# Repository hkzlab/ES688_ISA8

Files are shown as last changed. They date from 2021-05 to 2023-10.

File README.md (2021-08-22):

# ES688F / OPL3 8bit ISA Sound Card

## Introduction

This is a sound card for the ISA 8bit bus sporting the **ES688F** chip by *ESS Technology* and the **YMF262** chip by *Yamaha*, also known as the **OPL3**.

This board provides selectable **Sound Blaster PRO** / **Sound Blaster** emulation and **OPL3** compatibility.

It's completely jumper-configurable, requiring no software except the *essvol* utility to set the volume.

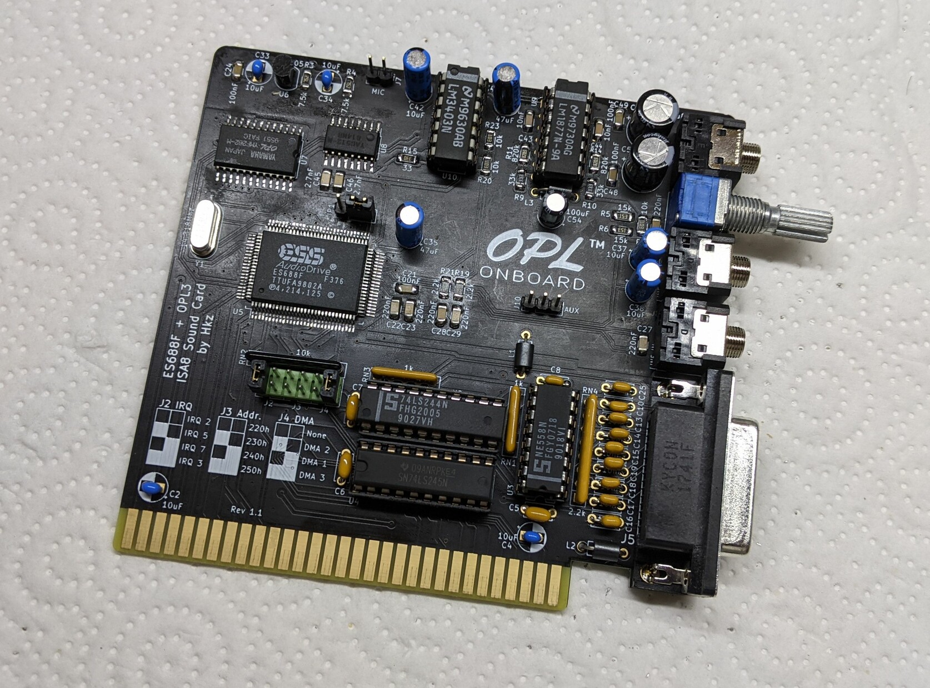
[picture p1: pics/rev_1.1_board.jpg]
Rev. 1.1 Board


This board provides the following connections:

* Speaker out (amplified)
* Line out
* Line in
* Aux in (internal header)
* Microphone in (internal header)
* Joystick port
* MIDI on Joystick port
* Volume regulation pot

### Disclaimer

I take NO responsibility for what happens if you decide to build and use this card. Your computer might crash, catch fire or be destroyed in other nasty ways.
You're encourauged to take what you deem fit from this, and use it in your projects!

### Functionalities

✅ means I tested the functionality and it works, ❌ means I tested the functionality and found issues, ? means that the functionality has yet to be tested.

* [✅] FM Synthesis via OPL3
* [✅] Digital audio playback
* [?] Stereo (left/right channel) check
* [✅] Joystick port
* [✅] Speaker Out (amplified)
* [✅] Line out
* [✅] Line in
* [?] AUX In
* [?] Microphone in
* [✅] MIDI output via Joystick port

The card was tested on:

* [✅] NEC V20 9.5Mhz / DOS 6.22
* [✅] SUNTAC 286 12Mhz motherboard / DOS 6.22

## Configuration

This card is configured via jumpers.

* **JP1**: Selects the **Sound Blaster emulation mode**
  * 1-2: Sound Blaster (DSP v2.11)
  * 2-3 Sound Blaster PRO (DSP v3.1)
  
The following jumpers must me insalled vertically in the block. **1** means **Jumper Present**, **0** means **Jumper Absent**.

* **J2**: Selects the IRQ:
  * 00: IRQ2
  * 10: IRQ5 (default)
  * 01: IRQ7
  * 11: IRQ3
* **J3**: Selects the I/O address:
  * 00: 220h (default)
  * 10: 230h
  * 01: 240h
  * 11: 250h
* **J4**: Selects the DMA channel
  * 00: None
  * 10: DMA2
  * 01: DMA1 (default)
  * 11: DMA3
  
  **WARNING**: /DACK2 and DRQ2 lines are disconnected and must be jumpered on the backside of the board if used, by bridging JP3 and JP2.

## Bill of Materials

**TODO**

## Known Issues

### Rev 1.1

* Missing silkscreen to describe JP1

### Rev 1.0

* Wrong footprints for YAC512 and YMF262 chips
* Volume pot placed after audio decoupling. Wrong.

## Credits

Thanks to [Sergey Kiselev](https://github.com/skiselev) for his symbol/footprint library!

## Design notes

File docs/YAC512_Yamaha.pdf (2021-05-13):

www.DataSheet4U.com

www.DataSheet4U.com

www.DataSheet4U.com

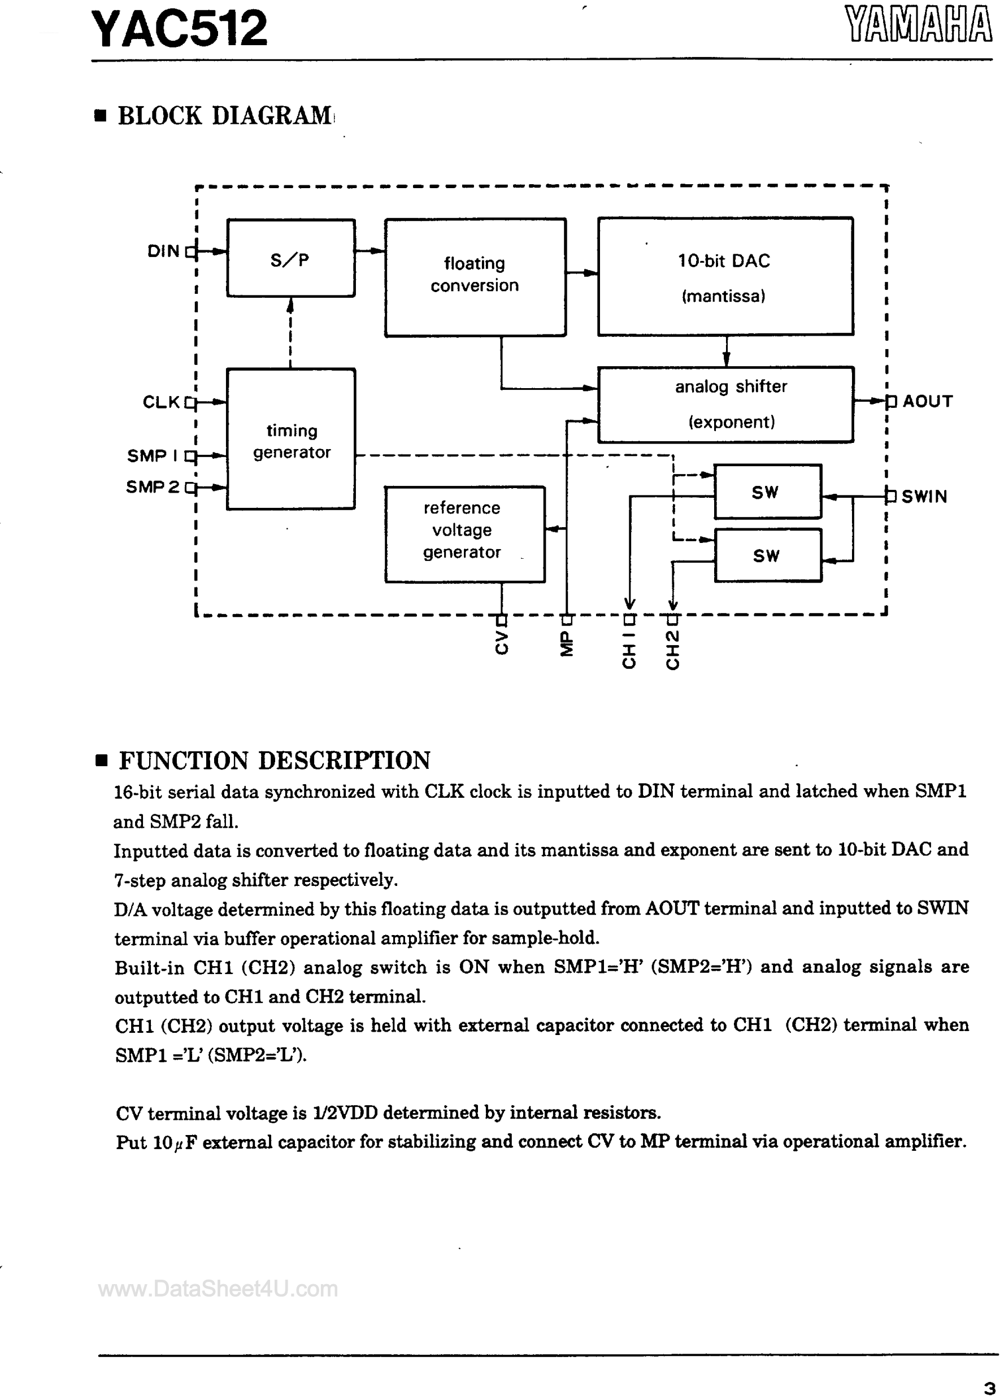
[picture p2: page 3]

www.DataSheet4U.com

www.DataSheet4U.com

www.DataSheet4U.com

www.DataSheet4U.com

www.DataSheet4U.com

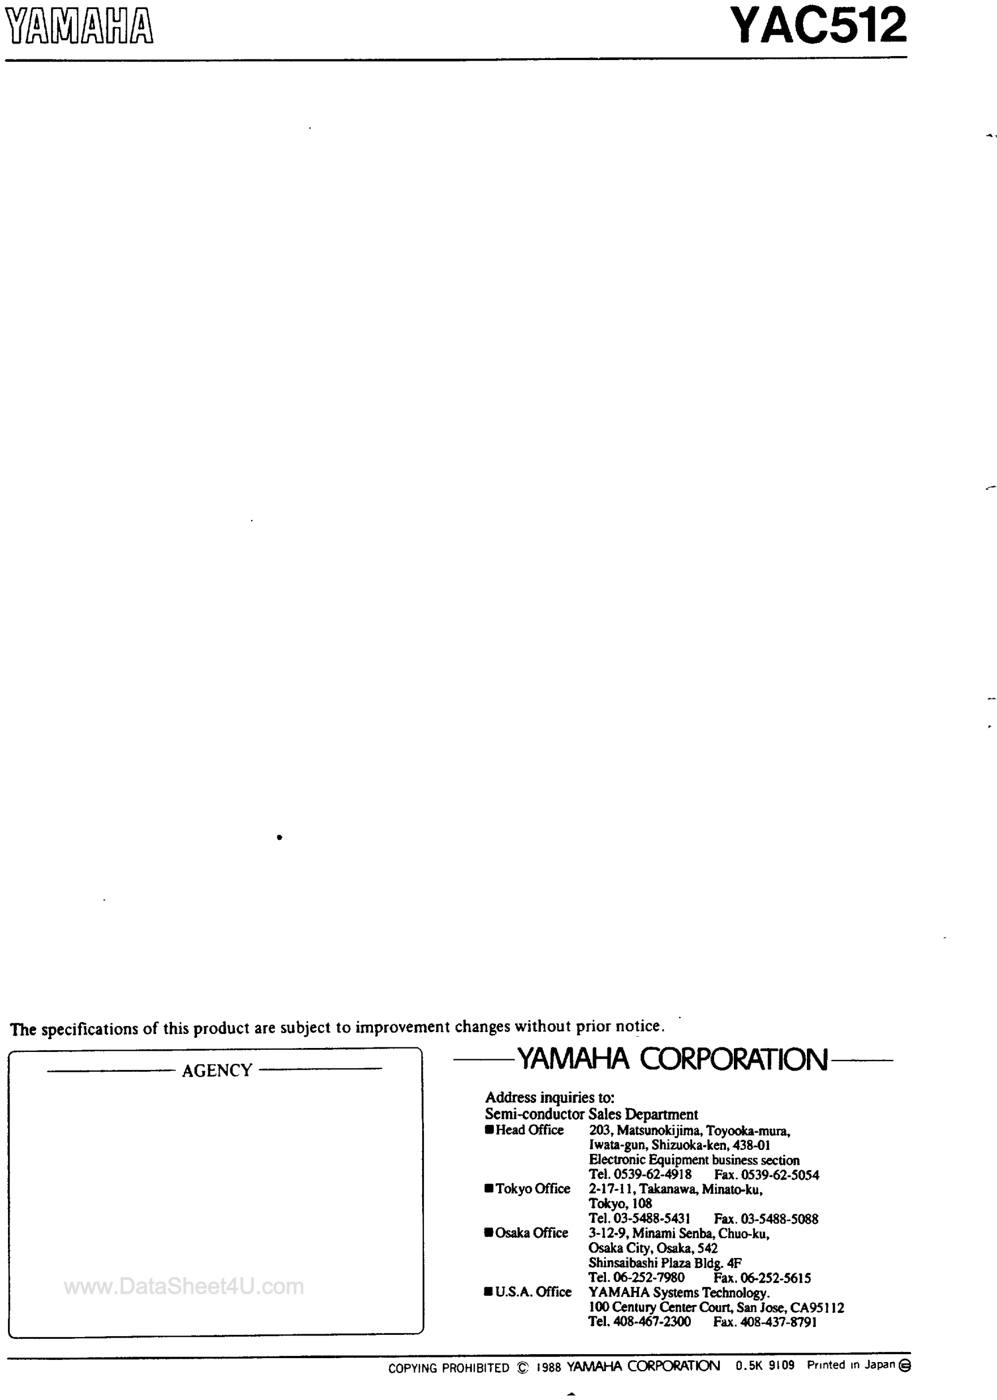
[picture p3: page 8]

www.DataSheet4U.com

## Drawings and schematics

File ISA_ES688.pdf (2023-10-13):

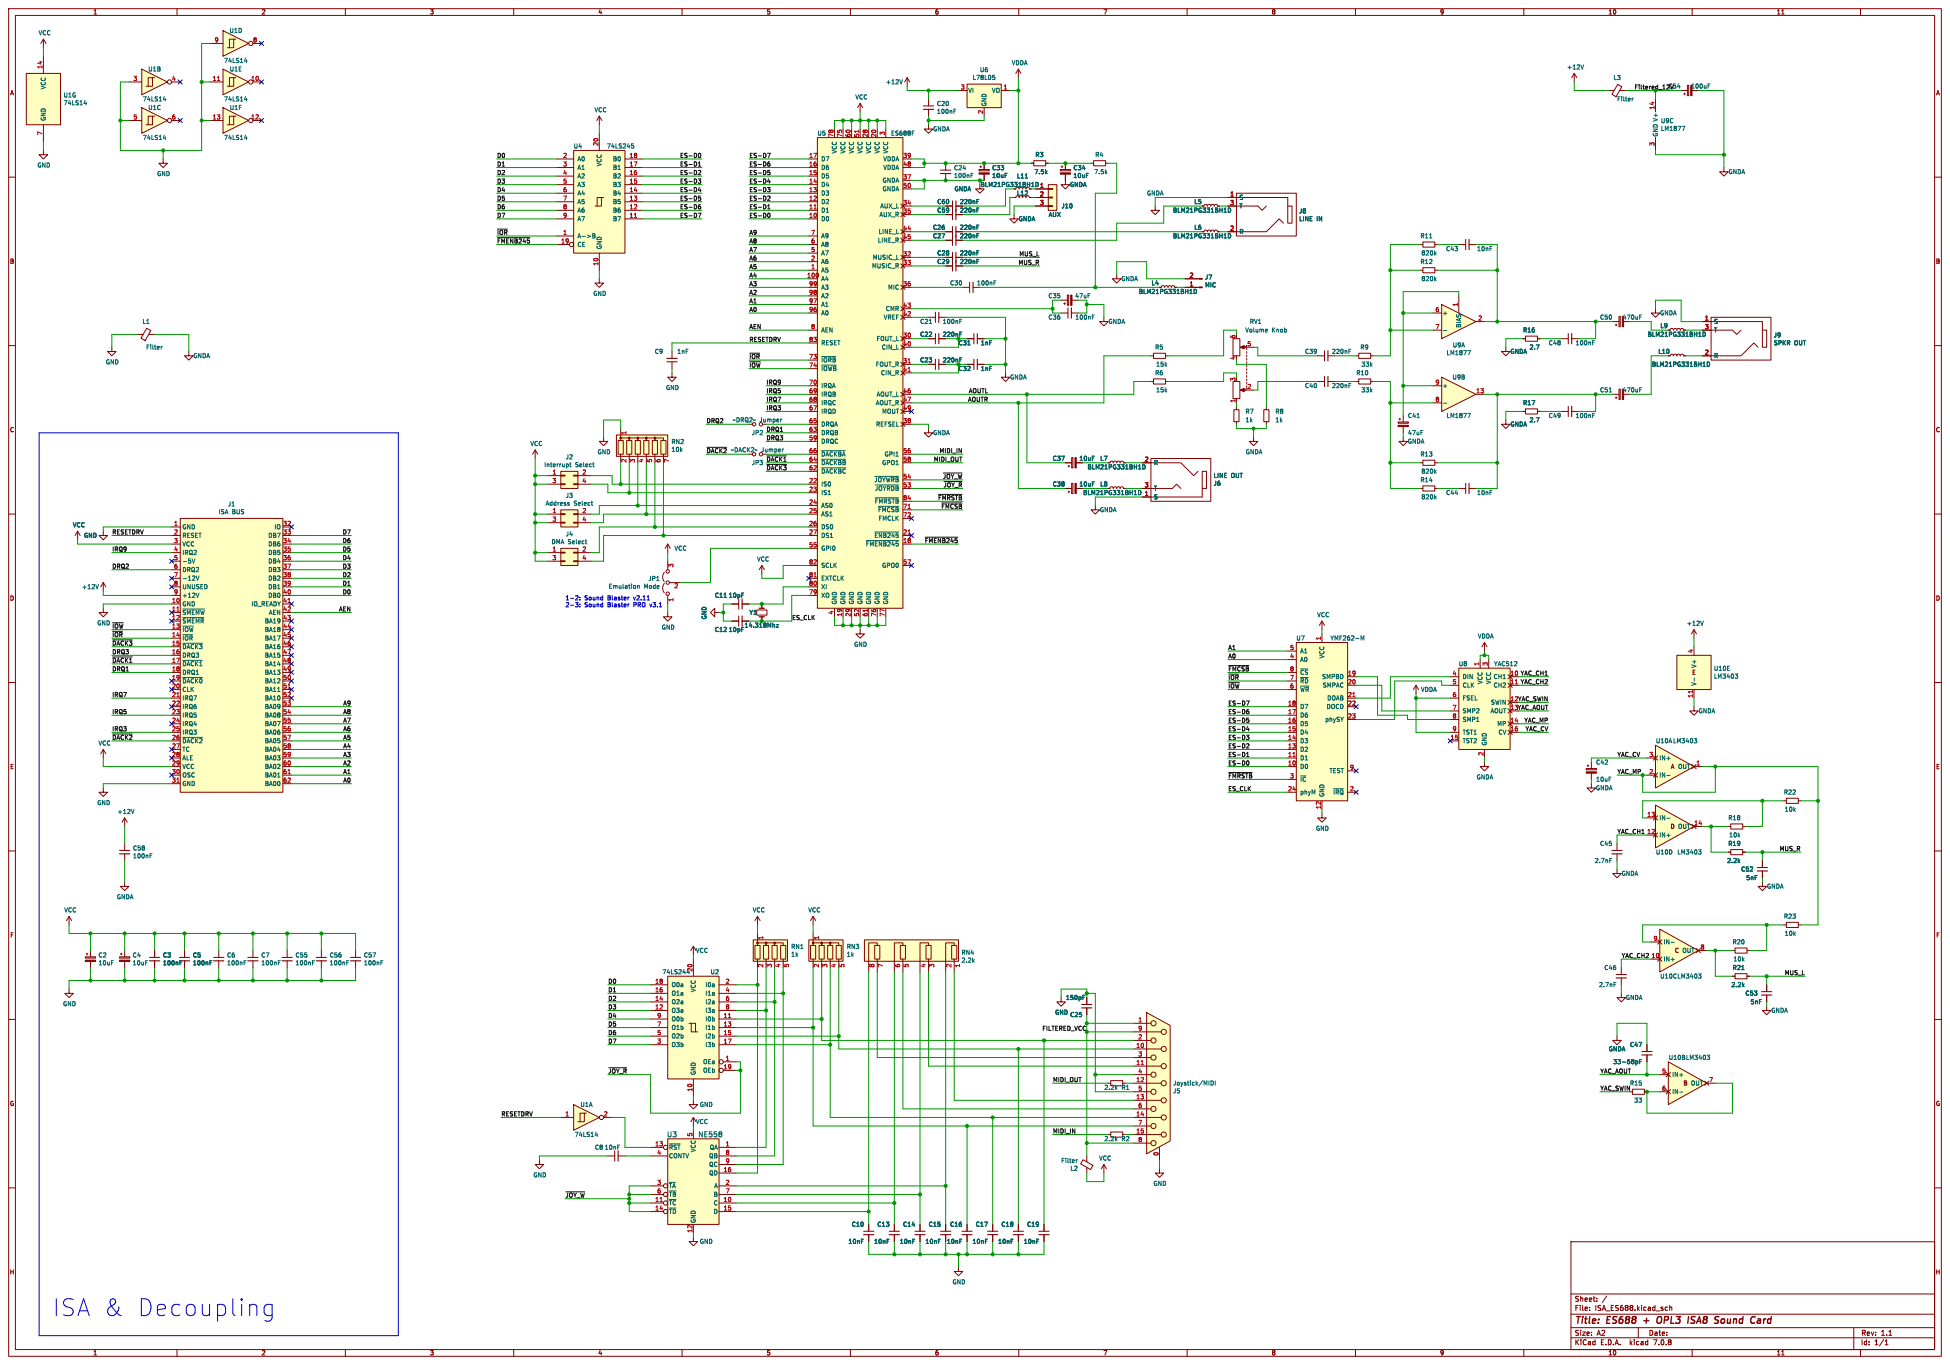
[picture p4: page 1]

3 FOUT_L 30 FOUT_R 31 MUSIC_L 32 MUSIC_R 33 AUX_L 34 AUX_R 35 MIC 36 GNDA 37 REFSEL 38 VDDA 39 GND

ES-D3 ES-D2 ES-D1 ES-D4 ~{IOW} D1

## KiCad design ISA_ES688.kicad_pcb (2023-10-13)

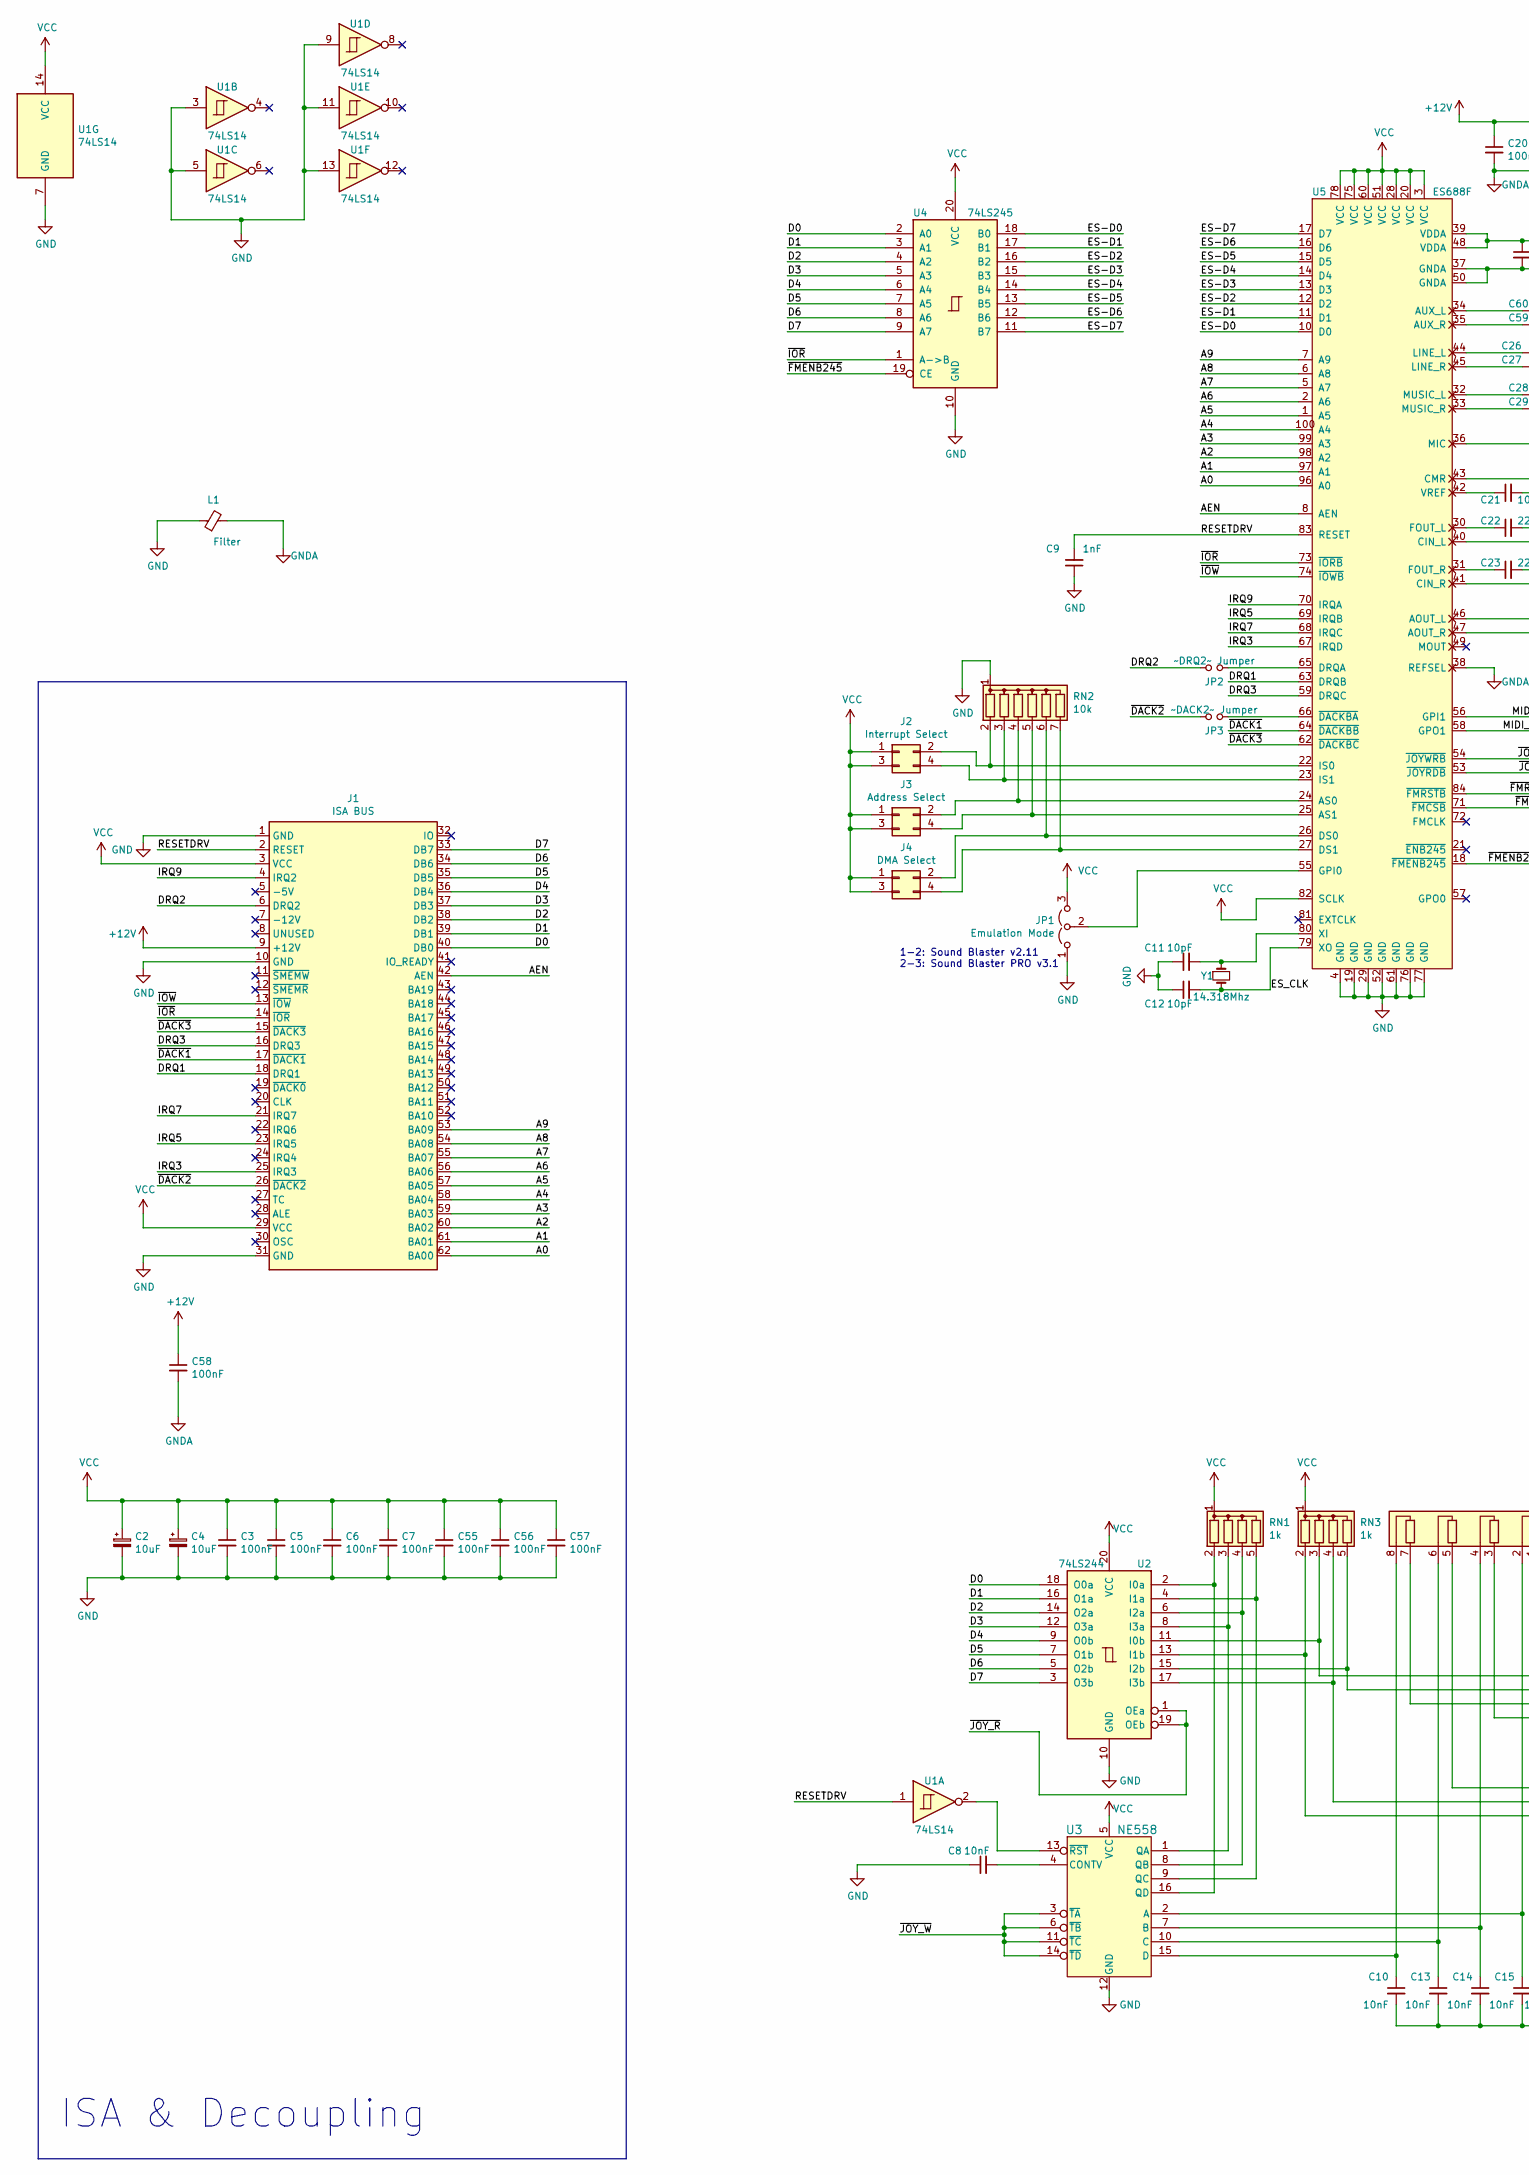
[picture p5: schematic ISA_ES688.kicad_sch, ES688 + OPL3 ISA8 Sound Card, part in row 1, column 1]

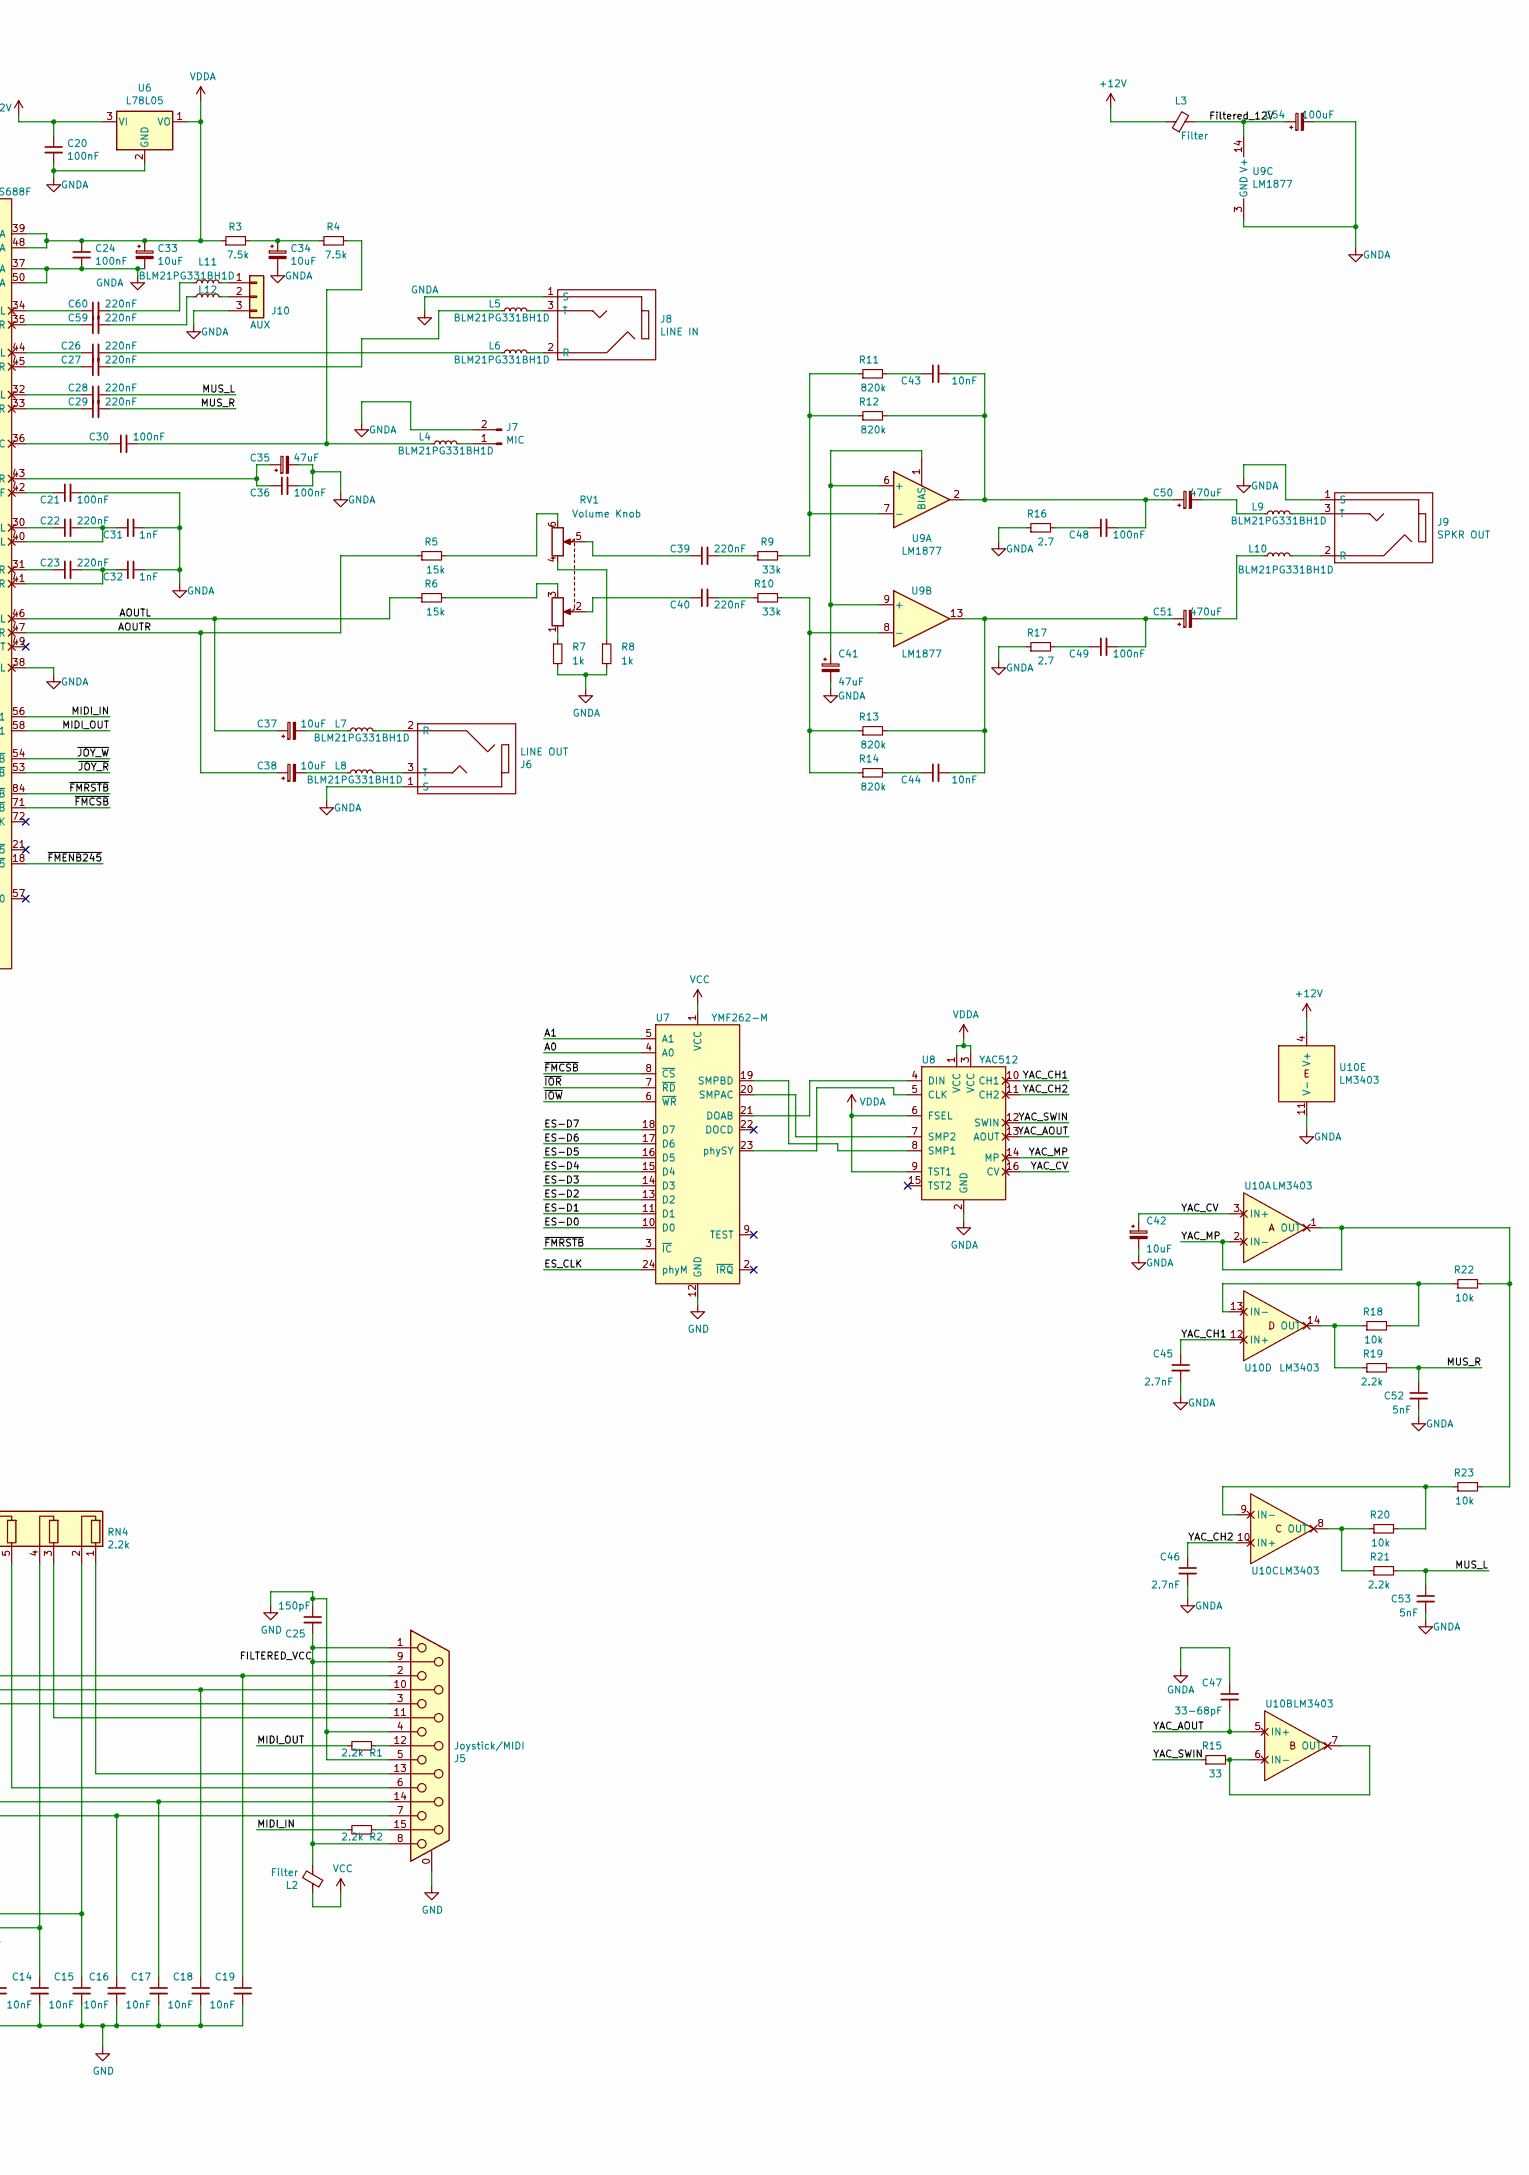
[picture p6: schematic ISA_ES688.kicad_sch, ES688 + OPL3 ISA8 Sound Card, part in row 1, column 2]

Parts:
C2, C4, C33, C34, C37, C38, C42: 10uF; CP_Radial_D5.0mm_P2.50mm
C3, C20, C21, C24, C30, C36, C48, C49, C55, C56, C57, C58: 100nF; C_1206_3216Metric_Pad1.33x1.80mm_HandSolder
C5, C6, C7: 100nF; C_Disc_D5.0mm_W2.5mm_P5.00mm
C8, C10, C13, C14, C15, C16, C17, C18, C19: 10nF; C_Disc_D5.0mm_W2.5mm_P5.00mm
C9, C31, C32: 1nF; C_1206_3216Metric_Pad1.33x1.80mm_HandSolder
C11, C12: 10pF; C_1206_3216Metric_Pad1.33x1.80mm_HandSolder
C22, C23, C26, C27, C28, C29, C39, C40, C59, C60: 220nF; C_1206_3216Metric_Pad1.33x1.80mm_HandSolder
C25: 150pF; C_Disc_D5.0mm_W2.5mm_P5.00mm
C35, C41: 47uF; CP_Radial_D5.0mm_P2.50mm
C43, C44: 10nF; C_1206_3216Metric_Pad1.33x1.80mm_HandSolder
C45, C46: 2.7nF; C_1206_3216Metric_Pad1.33x1.80mm_HandSolder
C47: 33-68pF; C_1206_3216Metric_Pad1.33x1.80mm_HandSolder
C50, C51: 470uF; CP_Radial_D8.0mm_P3.50mm
C52, C53: 5nF; C_1206_3216Metric_Pad1.33x1.80mm_HandSolder
C54: 100uF; CP_Radial_D5.0mm_P2.50mm
J1: ISA BUS; Conn_Edge_PCB_ISA8
J2: Interrupt Select; PinHeader_2x02_P2.54mm_Vertical
J3: Address Select; PinHeader_2x02_P2.54mm_Vertical
J4: DMA Select; PinHeader_2x02_P2.54mm_Vertical
J5: Joystick/MIDI; SB_DB15_152-3415
J6: LINE OUT; Conn_Audio_3.5mm_Stereo_SJ1-352XNG
J7: MIC; PinHeader_1x02_P2.54mm_Vertical
J8: LINE IN; Conn_Audio_3.5mm_Stereo_SJ1-352XNG
J9: SPKR OUT; Conn_Audio_3.5mm_Stereo_SJ1-352XNG
J10: AUX; PinHeader_1x03_P2.54mm_Vertical
JP1: Emulation Mode; PinHeader_1x03_P2.54mm_Vertical
JP2: ~DRQ2~ Jumper; SolderJumper-2_P1.3mm_Open_RoundedPad1.0x1.5mm
JP3: ~DACK2~ Jumper; SolderJumper-2_P1.3mm_Open_RoundedPad1.0x1.5mm
L1, L2, L3: Filter; L_Axial_L5.3mm_D2.2mm_P7.62mm_Horizontal_Vishay_IM-1
L4, L5, L6, L7, L8, L9, L10, L11: BLM21PG331BH1D; L_0805_2012Metric_Pad1.15x1.40mm_HandSolder
L12: 742792093; L_0805_2012Metric_Pad1.15x1.40mm_HandSolder
R1, R2, R19, R21: 2.2k; R_1206_3216Metric_Pad1.30x1.75mm_HandSolder
R3, R4: 7.5k; R_1206_3216Metric_Pad1.30x1.75mm_HandSolder
R5, R6: 15k; R_1206_3216Metric_Pad1.30x1.75mm_HandSolder
R7, R8: 1k; R_1206_3216Metric_Pad1.30x1.75mm_HandSolder
R9, R10: 33k; R_1206_3216Metric_Pad1.30x1.75mm_HandSolder
R11, R12, R13, R14: 820k; R_1206_3216Metric_Pad1.30x1.75mm_HandSolder
R15: 33; R_1206_3216Metric_Pad1.30x1.75mm_HandSolder
R16, R17: 2.7; R_1206_3216Metric_Pad1.30x1.75mm_HandSolder
R18, R20, R22, R23: 10k; R_1206_3216Metric_Pad1.30x1.75mm_HandSolder
RN1, RN3: 1k; R_Array_SIP5
RN2: 10k; R_Array_SIP7
RN4: 2.2k; R_Array_SIP8
RV1: Volume Knob; PTD902
U1: 74LS14; SOIC-14_3.9x8.7mm_P1.27mm
U2: 74LS244; DIP-20_W7.62mm
U3: NE558; DIP-16_W7.62mm
U4: 74LS245; DIP-20_W7.62mm
U5: ES688F; LQFP-14x20mm_P0.5mm
U6: L78L05; TO-92_Inline
U7: YMF262-M; SOP-24
U8: YAC512; SOP-16
U9: LM1877; DIP-14_W7.62mm_LongPads
U10: LM3403; DIP-14_W7.62mm
Y1: 14.318Mhz; Crystal_HC49-4H_Vertical

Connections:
+12V: C20.1, C58.1, J1.9 (+12V), L3.1, U6.3 (VI), U10.4 (V+)
/A0: J1.62 (BA00), U5.96 (A0), U7.4 (A0)
/A1: J1.61 (BA01), U5.97 (A1), U7.5 (A1)
/A2: J1.60 (BA02), U5.98 (A2)
/A3: J1.59 (BA03), U5.99 (A3)
/A4: J1.58 (BA04), U5.100 (A4)
/A5: J1.57 (BA05), U5.1 (A5)
/A6: J1.56 (BA06), U5.2 (A6)
/A7: J1.55 (BA07), U5.5 (A7)
/A8: J1.54 (BA08), U5.6 (A8)
/A9: J1.53 (BA09), U5.7 (A9)
/AEN: J1.42 (AEN), U5.8 (AEN)
/AOUTL: C37.1, R6.1, U5.46 (AOUT_L)
/AOUTR: C38.1, R5.1, U5.47 (AOUT_R)
/D0: J1.40 (DB0), U2.18 (O0a), U4.2 (A0)
/D1: J1.39 (DB1), U2.16 (O1a), U4.3 (A1)
/D2: J1.38 (DB2), U2.14 (O2a), U4.4 (A2)
/D3: J1.37 (DB3), U2.12 (O3a), U4.5 (A3)
/D4: J1.36 (DB4), U2.9 (O0b), U4.6 (A4)
/D5: J1.35 (DB5), U2.7 (O1b), U4.7 (A5)
/D6: J1.34 (DB6), U2.5 (O2b), U4.8 (A6)
/D7: J1.33 (DB7), U2.3 (O3b), U4.9 (A7)
/DRQ1: J1.18 (DRQ1), U5.63 (DRQB)
/DRQ2: J1.6 (DRQ2), JP2.1
/DRQ3: J1.16 (DRQ3), U5.59 (DRQC)
/ES-D0: U4.18 (B0), U5.10 (D0), U7.10 (D0)
/ES-D1: U4.17 (B1), U5.11 (D1), U7.11 (D1)
/ES-D2: U4.16 (B2), U5.12 (D2), U7.13 (D2)
/ES-D3: U4.15 (B3), U5.13 (D3), U7.14 (D3)
/ES-D4: U4.14 (B4), U5.14 (D4), U7.15 (D4)
/ES-D5: U4.13 (B5), U5.15 (D5), U7.16 (D5)
/ES-D6: U4.12 (B6), U5.16 (D6), U7.17 (D6)
/ES-D7: U4.11 (B7), U5.17 (D7), U7.18 (D7)
/ES_CLK: C12.2, U5.79 (XO), U7.24 (phyM), Y1.2
/FILTERED_VCC: C25.2, J5.1, J5.8, J5.9, L2.2
/Filtered_12V: C54.1, L3.2, U9.14 (V+)
/IRQ3: J1.25 (IRQ3), U5.67 (IRQD)
/IRQ5: J1.23 (IRQ5), U5.69 (IRQB)
/IRQ7: J1.21 (IRQ7), U5.68 (IRQC)
/IRQ9: J1.4 (IRQ2), U5.70 (IRQA)
/MIDI_IN: R2.2, U5.56 (GPI1)
/MIDI_OUT: R1.2, U5.58 (GPO1)
/MUS_L: C28.2, C53.1, R21.2
/MUS_R: C29.2, C52.1, R19.2
/RESETDRV: C9.2, J1.2 (RESET), U1.1, U5.83 (RESET)
/YAC_AOUT: C47.2, U8.13 (AOUT), U10.5 (IN+)
/YAC_CH1: C45.1, U8.10 (CH1), U10.12 (IN+)
/YAC_CH2: C46.1, U8.11 (CH2), U10.10 (IN+)
/YAC_CV: C42.1, U8.16 (CV), U10.3 (IN+)
/YAC_MP: R22.2, R23.2, U8.14 (MP), U10.1 (OUT), U10.2 (IN-)
/YAC_SWIN: R15.1, U8.12 (SWIN)
/~DACK1: J1.17 (~DACK1), U5.64 (~DACKBB)
/~DACK2: J1.26 (~DACK2), JP3.1
/~DACK3: J1.15 (~DACK3), U5.62 (~DACKBC)
/~FMCSB: U5.71 (~FMCSB), U7.8 (~CS)
/~FMENB245: U4.19 (CE), U5.18 (~FMENB245)
/~FMRSTB: U5.84 (~FMRSTB), U7.3 (~IC)
/~IOR: J1.14 (~IOR), U4.1 (A->B), U5.73 (~IORB), U7.7 (~RD)
/~IOW: J1.13 (~IOW), U5.74 (~IOWB), U7.6 (~WR)
/~JOY_R: U2.1 (OEa), U2.19 (OEb), U5.53 (~JOYRDB)
/~JOY_W: U3.3 (~TA), U3.6 (~TB), U3.11 (~TC), U3.14 (~TD), U5.54 (~JOYWRB)
GND: C2.2, C3.2, C4.2, C5.2, C6.2, C7.2, C8.1, C9.1, C10.2, C11.1, C12.1, C13.2, C14.2, C15.2, C16.2, C17.2, C18.2, C19.2, C25.1, C55.2, C56.2, C57.2, J1.1 (GND), J1.10 (GND), J1.31 (GND), J5.0 (PAD), J5.4, J5.5, JP1.1 (A), L1.1, RN2.1 (common), U1.3, U1.5, U1.7 (GND), U1.9, U1.11, U1.13, U2.10 (GND), U3.12 (GND), U4.10 (GND), U5.4 (GND), U5.19 (GND), U5.29 (GND), U5.52 (GND), U5.61 (GND), U5.76 (GND), U5.77 (GND), U7.12 (GND)
GNDA: C20.2, C21.2, C24.2, C31.2, C32.2, C33.2, C34.2, C35.2, C36.2, C41.2, C42.2, C45.2, C46.2, C47.1, C52.2, C53.2, C54.2, C58.2, J6.1 (S), J7.2, J8.1 (S), J9.1 (S), J10.3, L1.2, R7.2, R8.2, R16.1, R17.1, U5.37 (GNDA), U5.38 (REFSEL), U5.50 (GNDA), U6.2 (GND), U8.2 (GND), U9.3 (GND), U9.4 (GND), U9.5 (GND), U9.10 (GND), U9.11 (GND), U9.12 (GND), U10.11 (V-); also elsewhere on the board
unnamed: C8.2, U3.4 (CONTV)
unnamed: C10.1, RN4.8 (R4.2), U3.15 (D)
unnamed: C11.2, U5.80 (XI), Y1.1
unnamed: C13.1, RN4.6 (R3.2), U3.10 (C)
unnamed: C14.1, RN4.4 (R2.2), U3.7 (B)
unnamed: C15.1, RN4.2 (R1.2), U3.2 (A)
unnamed: C16.1, J5.7, RN3.2 (R1), U2.13 (I1b)
unnamed: C17.1, J5.14, RN3.4 (R3), U2.17 (I3b)
unnamed: C18.1, J5.10, RN3.5 (R4), U2.15 (I2b)
unnamed: C19.1, J5.2, RN3.3 (R2), U2.11 (I0b)
unnamed: C21.1, U5.42 (VREF)
unnamed: C22.1, U5.30 (FOUT_L)
unnamed: C22.2, C31.1, U5.40 (CIN_L)
unnamed: C23.1, U5.31 (FOUT_R)
unnamed: C23.2, C32.1, U5.41 (CIN_R)
unnamed: C26.1, U5.44 (LINE_L)
unnamed: C26.2, L6.1
unnamed: C27.1, U5.45 (LINE_R)
unnamed: C27.2, L5.1
unnamed: C28.1, U5.32 (MUSIC_L)
unnamed: C29.1, U5.33 (MUSIC_R)
unnamed: C30.1, U5.36 (MIC)
unnamed: C30.2, L4.1, R4.2
unnamed: C34.1, R3.2, R4.1
unnamed: C35.1, C36.1, U5.43 (CMR)
unnamed: C37.2, L7.1
unnamed: C38.2, L8.1
unnamed: C39.2, R9.1
unnamed: C40.2, R10.1
unnamed: C41.1, U9.1 (BIAS), U9.6 (+), U9.9 (+)
unnamed: C43.1, R11.2
unnamed: C43.2, C48.2, C50.1, R12.2, U9.2
unnamed: C44.1, R14.2
unnamed: C44.2, C49.2, C51.1, R13.2, U9.13
unnamed: C48.1, R16.2
unnamed: C49.1, R17.2
unnamed: C50.2, L9.1
unnamed: C51.2, L10.1
unnamed: C59.1, U5.35 (AUX_R)
unnamed: C59.2, L12.1
unnamed: C60.1, U5.34 (AUX_L)
unnamed: C60.2, L11.1
unnamed: J2.2, RN2.2 (R1), U5.22 (IS0)
unnamed: J2.4, RN2.3 (R2), U5.23 (IS1)
unnamed: J3.2, RN2.4 (R3), U5.24 (AS0)
unnamed: J3.4, RN2.5 (R4), U5.25 (AS1)
unnamed: J4.2, RN2.6 (R5), U5.26 (DS0)
unnamed: J4.4, RN2.7 (R6), U5.27 (DS1)
unnamed: J5.3, RN4.7 (R4.1)
unnamed: J5.6, RN4.5 (R3.1)
unnamed: J5.11 (P111), RN4.3 (R2.1)
unnamed: J5.12, R1.1
unnamed: J5.13, RN4.1 (R1.1)
unnamed: J5.15, R2.1
unnamed: J6.2 (R), L7.2
unnamed: J6.3 (T), L8.2
unnamed: J7.1, L4.2
unnamed: J8.2 (R), L6.2
unnamed: J8.3 (T), L5.2
unnamed: J9.2 (R), L10.2
unnamed: J9.3 (T), L9.2
unnamed: J10.1, L11.2
unnamed: J10.2, L12.2
unnamed: JP1.2 (C), U5.55 (GPI0)
unnamed: JP2.2, U5.65 (DRQA)
unnamed: JP3.2, U5.66 (~DACKBA)
unnamed: R5.2, RV1.6
unnamed: R6.2, RV1.3
unnamed: R10.2, R13.1, R14.1, U9.8 (-)
unnamed: R9.2, R11.1, R12.1, U9.7 (-)
unnamed: R15.2, U10.6 (IN-), U10.7 (OUT)
unnamed: R18.1, R19.1, U10.14 (OUT)
unnamed: R18.2, R22.1, U10.13 (IN-)
unnamed: R20.1, R21.1, U10.8 (OUT)
unnamed: R20.2, R23.1, U10.9 (IN-)
unnamed: RN1.2 (R1), U2.2 (I0a), U3.16 (QD)
unnamed: RN1.3 (R2), U2.8 (I3a), U3.1 (QA)
unnamed: RN1.4 (R3), U2.6 (I2a), U3.8 (QB)
unnamed: RN1.5 (R4), U2.4 (I1a), U3.9 (QC)
unnamed: U1.2, U3.13 (~RST)
unnamed: U7.19 (SMPBD), U8.8 (SMP1)
unnamed: U7.20 (SMPAC), U8.7 (SMP2)
unnamed: U7.21 (DOAB), U8.4 (DIN)
unnamed: U7.23 (phySY), U8.5 (CLK)
VCC: C2.1, C3.1, C4.1, C5.1, C6.1, C7.1, C55.1, C56.1, C57.1, J1.3 (VCC), J1.29 (VCC), J2.1, J2.3, J3.1, J3.3, J4.1, J4.3, JP1.3 (B), L2.1, RN1.1 (common), RN3.1 (common), U1.14 (VCC), U2.20 (VCC), U3.5 (VCC), U4.20 (VCC), U5.3 (VCC), U5.20 (VCC), U5.28 (VCC), U5.51 (VCC), U5.60 (VCC), U5.75 (VCC), U5.78 (VCC), U5.82 (SCLK), U7.1 (VCC)
VDDA: C24.1, C33.1, R3.1, U5.39 (VDDA), U5.48 (VDDA), U6.1 (VO), U8.1 (VCC), U8.3 (VCC), U8.6 (FSEL), U8.9 (TST1)

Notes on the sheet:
ISA & Decoupling
1-2: Sound Blaster v2.11 2-3: Sound Blaster PRO v3.1

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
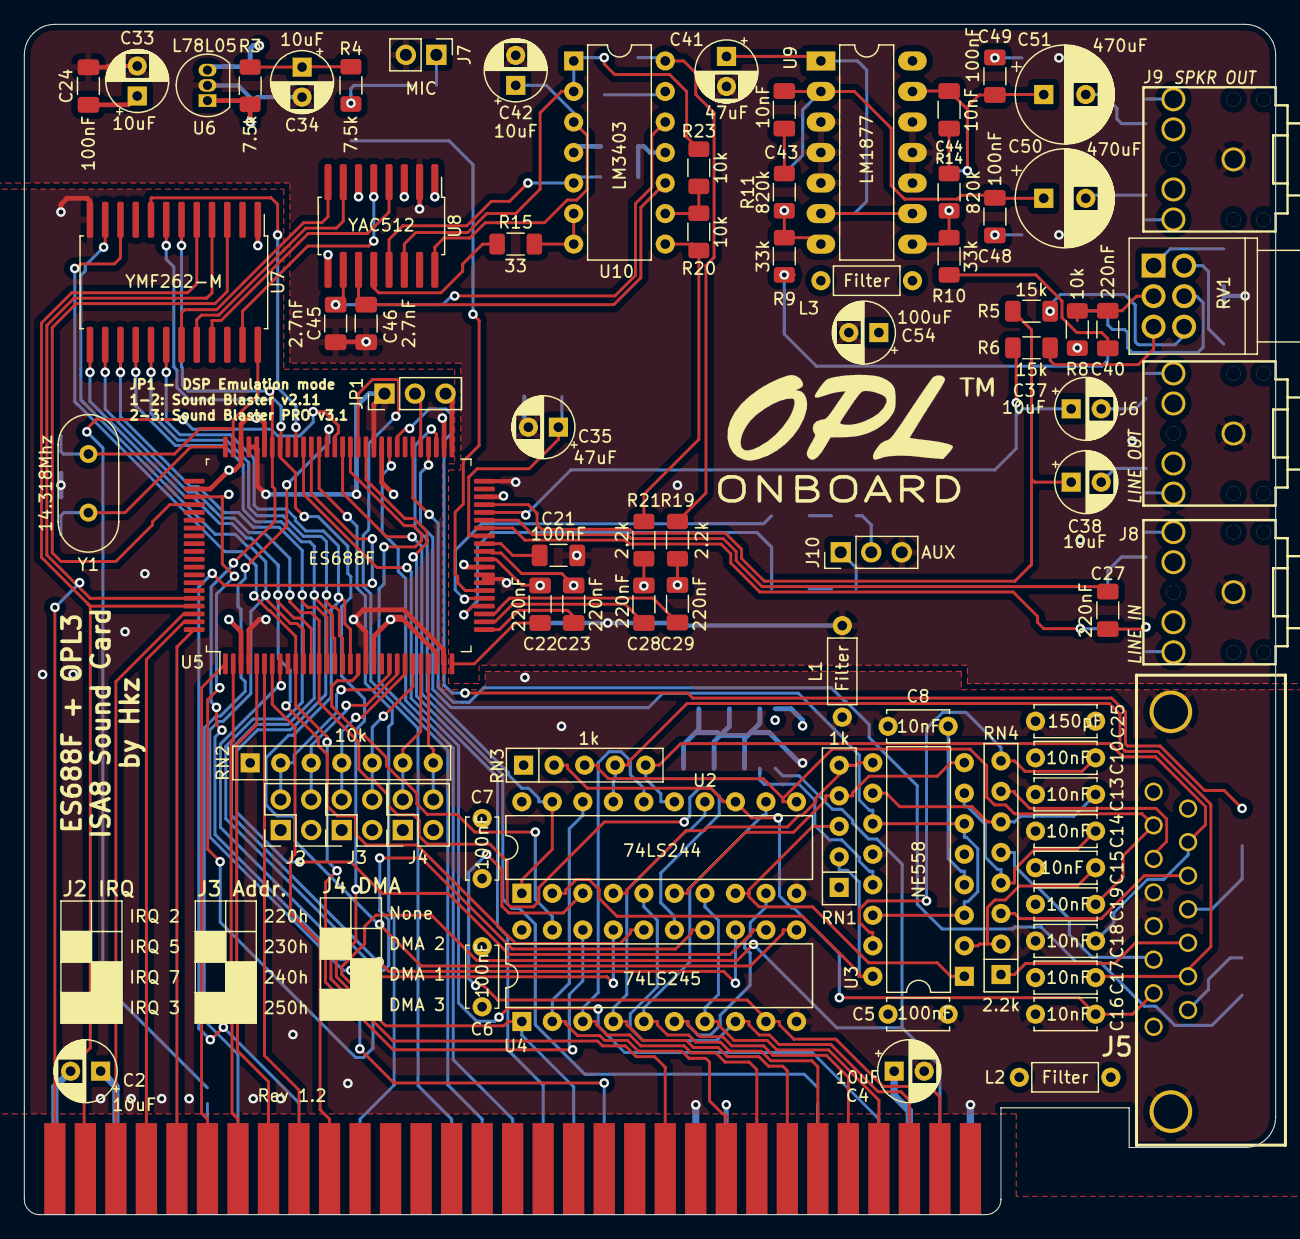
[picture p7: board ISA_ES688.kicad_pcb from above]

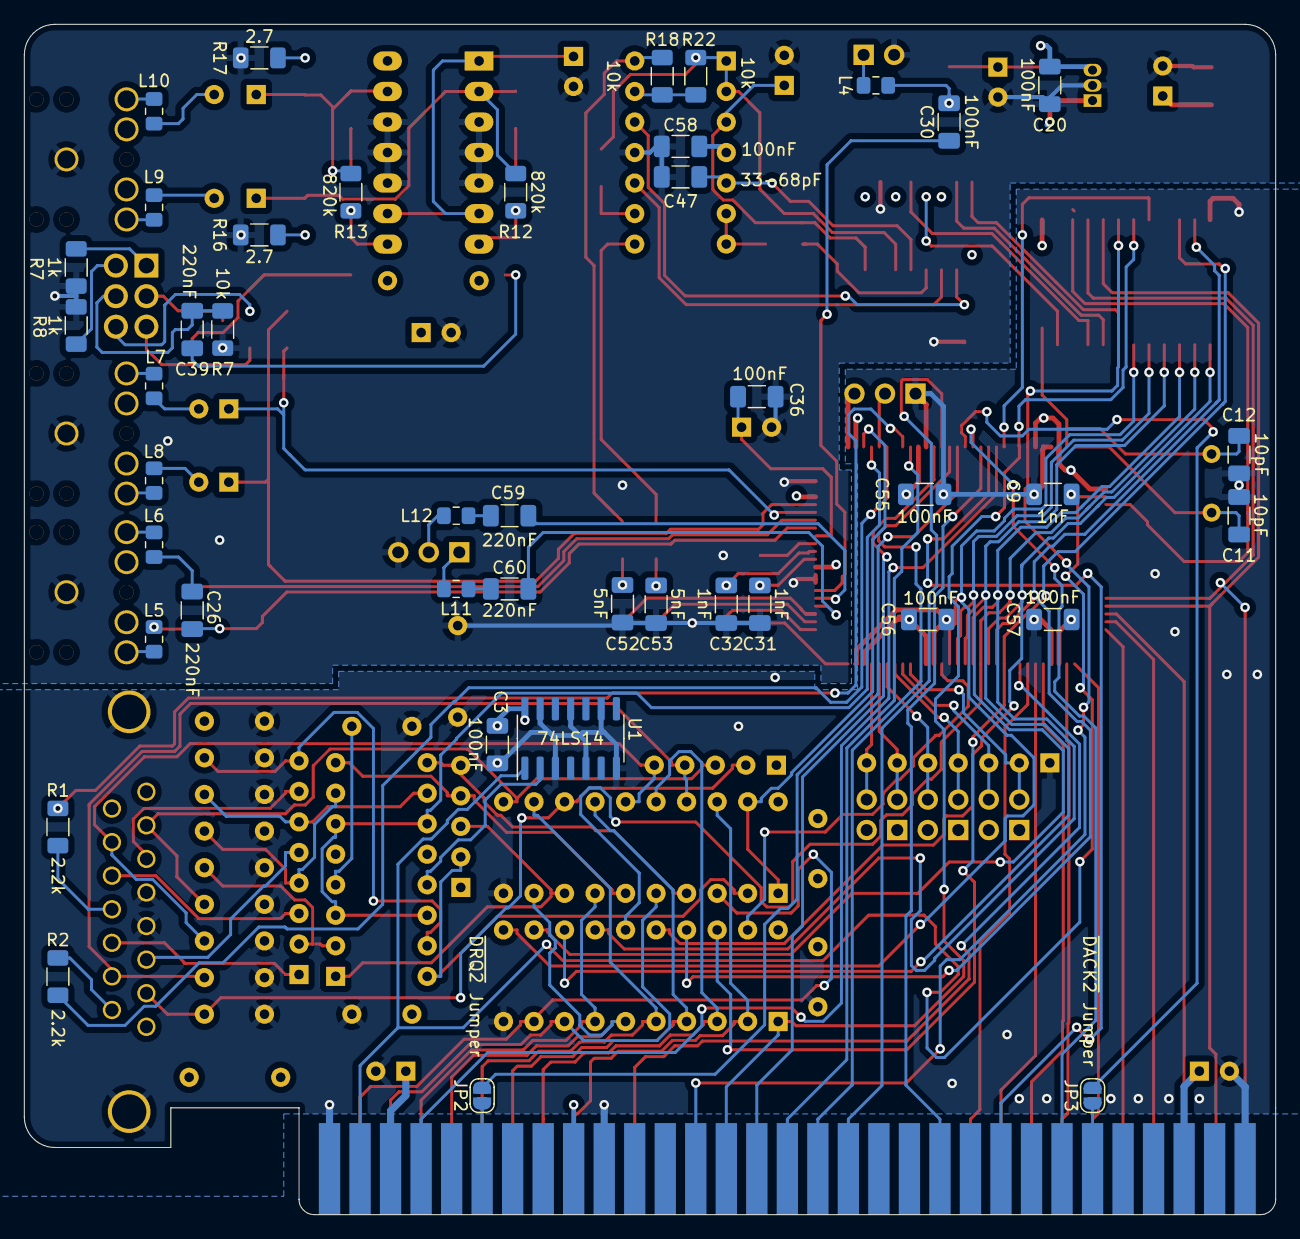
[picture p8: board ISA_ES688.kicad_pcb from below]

Board: 4 copper layers, 104.1 x 99.1 mm, 125 parts (43 on the bottom side), 153 nets.

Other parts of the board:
R7#2, R8#2: 1k; R_1206_3216Metric_Pad1.30x1.75mm_HandSolder

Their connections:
GNDA: R7#2.2, R8#2.2; also elsewhere on the board

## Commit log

2021-05-13 Begin creating the ES866F symbol
    [ISA_ES688.kicad_pcb, ISA_ES688.sch]
2021-05-13 Pin changes for ES688
2021-05-14 Add NE558 symbol
    [ISA_ES688.sch]
2021-05-14 Begin changing the schematics
    [ISA_ES688.sch]
2021-05-14 Remove some unused components
    [ISA_ES688.sch]
2021-05-14 Complete more schematic
    [ISA_ES688.sch]
2021-05-14 Cleanup for joystick part
    [ISA_ES688.sch]
2021-05-14 More joystick schematics
    [ISA_ES688.sch]
2021-05-14 Add gnd connection to caps for joystick
    [ISA_ES688.sch]
2021-05-14 Add VDDA symbol
    [ISA_ES688.sch]
2021-05-14 Replace resistor network
    [ISA_ES688.sch]
2021-05-15 Add more components to schematic
    [ISA_ES688.sch]
2021-05-15 Start wiring the OPL3 to the ES688 chip
    [ISA_ES688.sch]
2021-05-15 Connect OPL3 to YAC512
    [ISA_ES688.sch]
2021-05-15 Begin reversing opamp schematic
    [ISA_ES688.sch]
2021-05-15 Implement part of OPAMP circuit
    [ISA_ES688.sch]
2021-05-15 Mark more pins as not connected
    [ISA_ES688.sch]
2021-05-15 Rewire midi connection
    [ISA_ES688.sch]
2021-05-15 Reorganize connections a bit
    [ISA_ES688.sch]
2021-05-16 More OP-AMP circuit
    [ISA_ES688.sch]
2021-05-16 Completed OPAMP circuit?
    [ISA_ES688.sch]
2021-05-16 Add volume pot footprint, and volume control to sch
    [ISA_ES688.sch]
2021-05-17 Begin assigning footprints
    [ISA_ES688.sch]
2021-05-17 Assign more footprints
    [ISA_ES688.sch]
2021-05-17 Finished assigning footprints
    [ISA_ES688.sch]
2021-05-18 Begin laying out parts
    [ISA_ES688.kicad_pcb, ISA_ES688.sch]
2021-05-18 Begin placing some components on the board
    [ISA_ES688.kicad_pcb, ISA_ES688.sch]
2021-05-18 More placing on PCB
    [ISA_ES688.kicad_pcb]
2021-05-18 More placements
    [ISA_ES688.kicad_pcb]
2021-05-18 More movement on PCB
    [ISA_ES688.kicad_pcb, ISA_ES688.sch]
2021-05-18 Additional trace routing
    [ISA_ES688.kicad_pcb, ISA_ES688.sch]
2021-05-18 Placed all components on PCB
    [ISA_ES688.kicad_pcb, ISA_ES688.sch]
2021-05-18 More routing for audio part
    [ISA_ES688.kicad_pcb]
2021-05-18 More routing
    [ISA_ES688.kicad_pcb]
2021-05-18 Routed audio section
    [ISA_ES688.kicad_pcb]
2021-05-18 Completed routing of board
    [ISA_ES688.kicad_pcb, ISA_ES688.sch]
2021-05-18 Added descriptions to silkscreen
    [ISA_ES688.kicad_pcb]
2021-05-18 Another silkscreen fix
    [ISA_ES688.kicad_pcb]
2021-05-18 Updated footprint size
    [ISA_ES688.kicad_pcb]
2021-05-19 Slightly reroute a trace
    [ISA_ES688.kicad_pcb]
2021-05-19 Refill zones
    [ISA_ES688.kicad_pcb]
2021-05-19 Added two resistors after the volume pot
    [ISA_ES688.kicad_pcb, ISA_ES688.sch]
2021-05-20 Fix some traces in gnd plane
    [ISA_ES688.kicad_pcb, ISA_ES688.sch]
2021-05-23 Moved some connectors and change DB15 footprint
    [ISA_ES688.kicad_pcb, ISA_ES688.sch]
2021-05-24 Add keystone bracket
    [ISA_ES688.kicad_pcb]
2021-05-25 Move components to use the keystone 9200-3 bracket
    [ISA_ES688.kicad_pcb]
2021-05-25 Change spacing in jumper's silkscreen
    [ISA_ES688.kicad_pcb]
2021-05-26 Replaced two ceramics caps with electrolitics
    [ISA_ES688.kicad_pcb, ISA_ES688.sch]
2021-05-26 Heavier 12V trace
    [ISA_ES688.kicad_pcb]
2021-05-26 More ground plane!
    [ISA_ES688.kicad_pcb]
2021-06-12 Move connectors slightly forward
    [ISA_ES688.kicad_pcb]
2021-06-12 Rerouted some traces
    [ISA_ES688.kicad_pcb]
2021-06-16 Changed silkscreen for IRQ
    [ISA_ES688.kicad_pcb]
2021-06-16 Fattened some tracks
    [ISA_ES688.kicad_pcb]
2021-06-16 Fixed some more silkscreen
    [ISA_ES688.kicad_pcb]
2021-06-16 Add gerbers for rev 1.0
2021-06-17 Fixed AEN pin name
2021-07-01 Add new footprints for SOP16 and 24
    [ISA_ES688.kicad_pcb, ISA_ES688.sch]
2021-07-01 Redraw part of the PCB to conform to new footprints
    [ISA_ES688.kicad_pcb, ISA_ES688.sch]
2021-07-01 Fix silkscreen
    [ISA_ES688.kicad_pcb]
2021-07-01 Another fix to silkscreen
    [ISA_ES688.kicad_pcb]
2021-07-02 Updated silkscreen and version on schematic
    [ISA_ES688.kicad_pcb, ISA_ES688.sch]
2021-07-02 Reroute some traces
    [ISA_ES688.kicad_pcb]
2021-07-03 Change configuration pin description
    [ISA_ES688.kicad_pcb]
2021-07-03 Add OPL logo
    [ISA_ES688.kicad_pcb]
2021-07-03 Change silkscreen
    [ISA_ES688.kicad_pcb]
2021-07-03 Further silkscreen changes
    [ISA_ES688.kicad_pcb]
2021-07-03 More silkscreen adjustments
    [ISA_ES688.kicad_pcb]
2021-07-04 Enlarged footprints for YAC and OPL, again
    [ISA_ES688.kicad_pcb]
2021-07-05 Another small silkscreen fix
    [ISA_ES688.kicad_pcb]
2021-07-07 Add note in schematic
    [ISA_ES688.sch]
2021-07-07 Moved the potentiometer for volume before decoupling
    [ISA_ES688.kicad_pcb, ISA_ES688.sch]
2021-07-07 Reroute some tracks
    [ISA_ES688.kicad_pcb]
2021-07-09 Add headers for aux port
    [ISA_ES688.kicad_pcb, ISA_ES688.sch]
2021-07-10 Add ferrite beads at outputs and inputs
    [ISA_ES688.kicad_pcb, ISA_ES688.sch]
2021-07-11 Update beads used for audio lines
    [ISA_ES688.kicad_pcb, ISA_ES688.sch]
2021-07-19 Changed fixed resistor values for potentiometer
    [ISA_ES688.kicad_pcb, ISA_ES688.sch]
2021-07-19 Fix name in schematic
    [ISA_ES688.sch]
2021-07-27 Add rev 1.1 gerbers
    [ISA_ES688.kicad_pcb]
2021-07-27 Add 1.1 gerbers
2021-08-14 Added silkscreen for JP1
    [ISA_ES688.kicad_pcb]
2021-08-15 Move tweak silkscreen
    [ISA_ES688.kicad_pcb]
2021-11-09 Update KiCad url
2023-10-13 Initial import to Kicad 7
    [ISA_ES688.kicad_pcb, ISA_ES688.kicad_sch, ISA_ES688.sch]
